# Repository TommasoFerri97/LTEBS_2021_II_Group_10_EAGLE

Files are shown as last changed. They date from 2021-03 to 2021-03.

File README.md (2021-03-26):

# Electronic technologies and biosensors laboratory
> 2021 - II semester - First Assignment

## Authors (Group 10)
  - [**Dario Comini**](https://github.com/DarioComini) 
  - [**Tommaso Ferri**](https://github.com/TommasoFerri97)

## Description
Design a schematic, a PCB, and custom devices using Autodesk EAGLE software.

### Context
Your company, the LTEBS srl, would like to use the PSoC 5LP micro-controller in a project requested by a customer. In order to evaluate the performance of the micro-controller and to determine if such uC is suitable for the project, the R&D department would like to design a PCB embedding the PSoC 5LP. This way, testing and assessment of the performance would be a lot easier than using a simple breadboard. As Cypress offers a development kit for the PSoC 5LP, namely the CY8CKIT-059, you are requested to design a PCB embedding suck kit, which will be soldered on male jumpers, and additional components required to conduct the proper testing by the R&D department. As some of the requested components are not present in EAGLE installation libraries, you are required to design a library containing such components. The PCB will be manufactured by [MDSrl](https://www.mdsrl.it/).

Starting from a schematic and a list of components, create the associated PCB. Route all the components, and check that the ratsnest command does not provide any error message. Create a design rule files according to the technical specifications reported in the manufacturer website. Perform a DRC (Design Rule Check) using the created DRC file and check that no error or warning is generated.

### Repository structure
- **Library**: Contains EAGLE library files
  - *"Group_10_Library.lbr"*: library file for devices [TMUX1208](https://www.ti.com/lit/ds/symlink/tmux1208.pdf) and [TCA9546A](https://www.ti.com/lit/ds/symlink/tca9546a.pdf)
- **Project**: Contains EAGLE schematic and board files
  - *"Group_10.sch"*: schematic file
  - *"Group_10.brd"*: board file
- **Design Rules**: Contains EAGLE design rules file
  - *"Group_10.dru"*: design rules file, following [manufacturer's specifications](https://www.mdsrl.it/mddesignrules.html)

### Additional resources
The following documents/tutorial can be useful for this assignment:
- [SparkFun EAGLE Tutorial](https://learn.sparkfun.com/tutorials/using-eagle-schematic/all)
- [EAGLE Layers](https://www.autodesk.com/products/eagle/blog/every-layer-explained-autodesk-eagle/)
- [Getting Started with EAGLE](https://www.autodesk.com/products/eagle/overview)

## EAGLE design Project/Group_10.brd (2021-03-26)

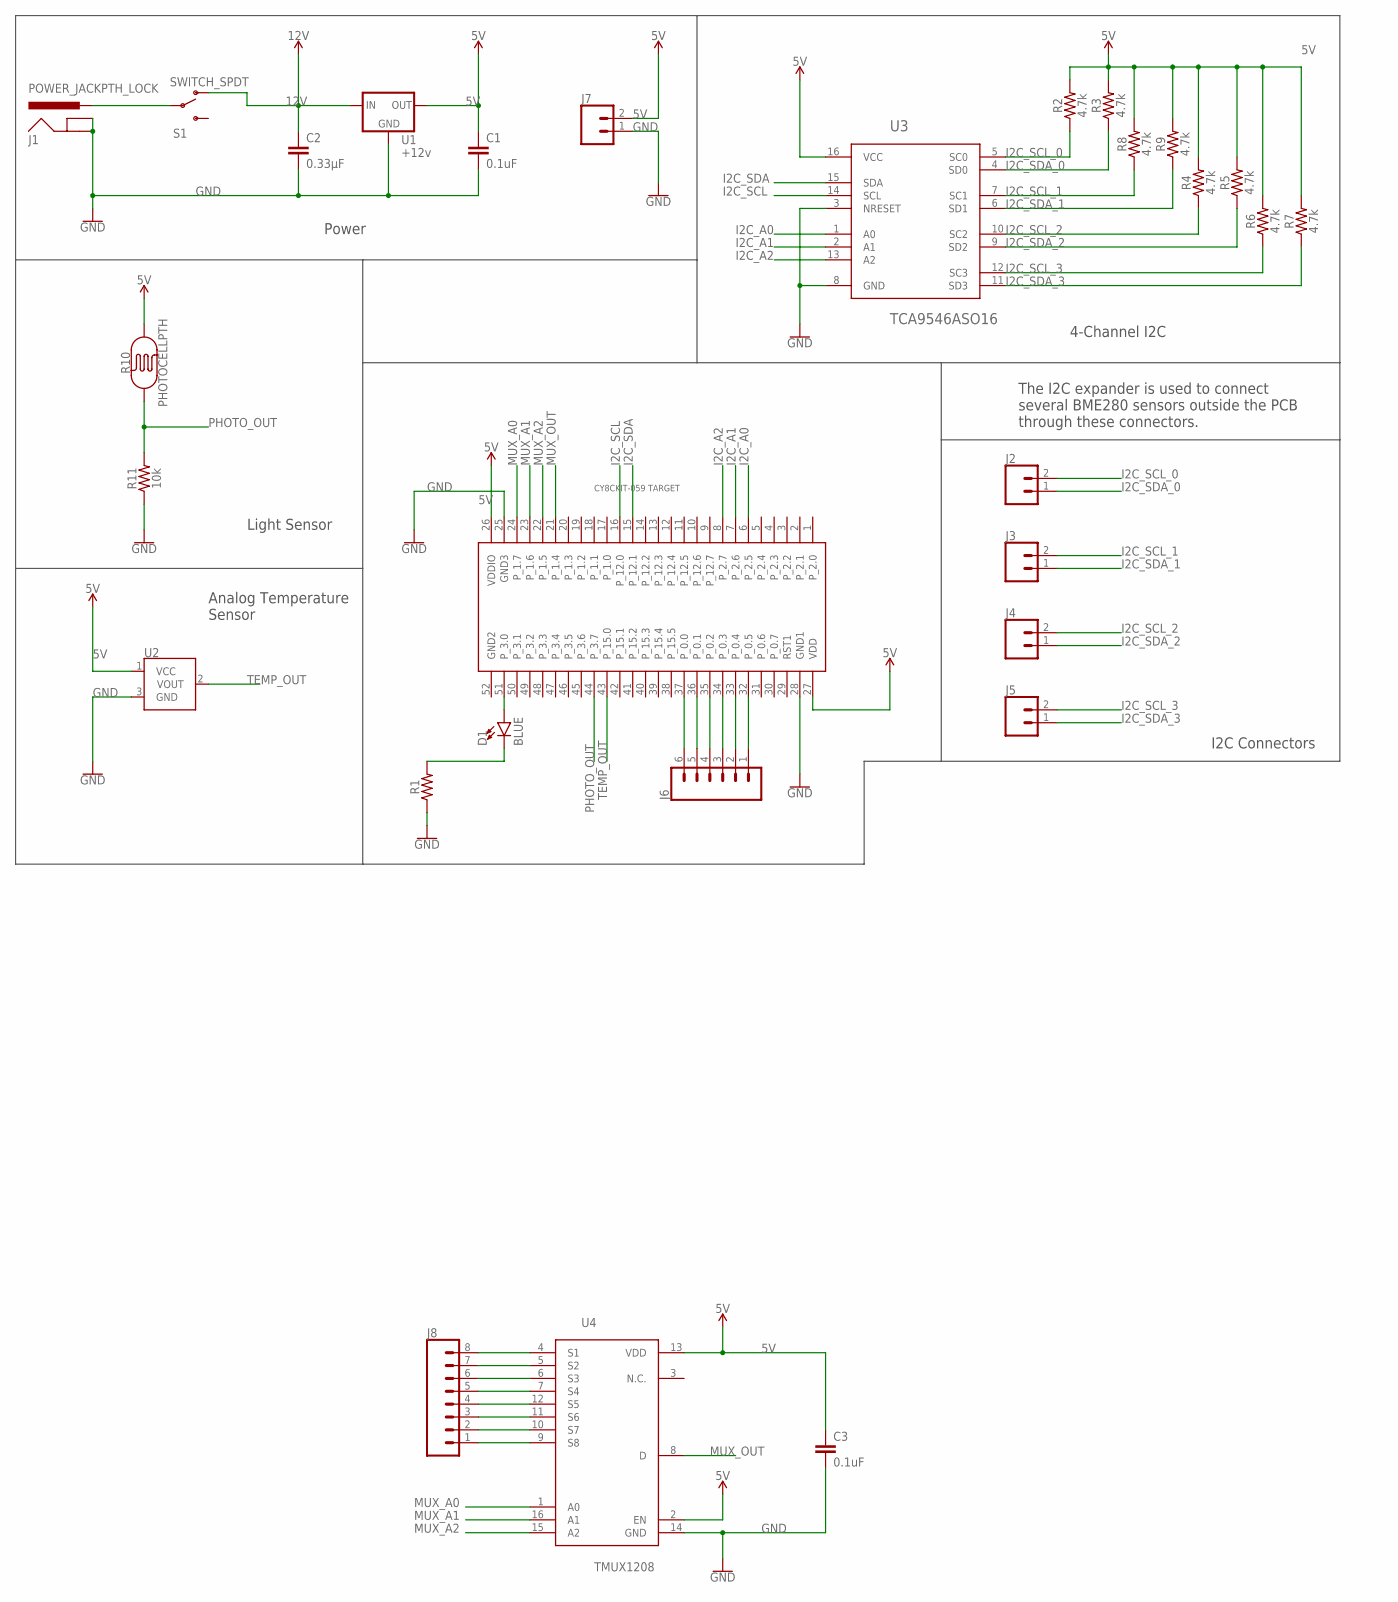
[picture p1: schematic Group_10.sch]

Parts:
C1, C3: 0.1uF; CAP-PTH-SMALL-KIT
C2: 0.33µF; 0805
D1: BLUE; LED-1206
J1: POWER_JACKPTH_LOCK; POWER_JACK_PTH_LOCK
J2, J3, J4, J5, J7: CONN_02; 1X02
J6: CONN_06LOCK; 1X06_LOCK
J8: CONN_08"; 1X08
R1: AXIAL-0.3
R2, R3, R4, R5, R6, R7, R8, R9: 4.7k; 0603
R10: PHOTOCELLPTH; PHOTOCELL
R11: 10k; 0603
S1: SWITCH_SPDT; KPS-1290
U1: +12v; TO-252
U2: TMP36GT9; TO-92
U3: TCA9546ASO16; TSSOP16
U4: TMUX1208; QFN16
U$2: CY8CKIT-059_TARGET_3

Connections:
5V: C1.1, C3.1, J7.2, R2.2, R3.2, R4.2, R5.2, R6.2, R7.2, R8.2, R9.2, R10.2, U1.2 (OUT), U2.1 (VCC), U3.16 (VCC), U4.2 (EN), U4.13 (VDD), U$2.26 (VDDIO), U$2.27 (VDD)
12V: C2.1, S1.O, U1.1 (IN)
GND: C1.2, C2.2, C3.2, J1.GND, J1.GNDBREAK, J7.1, R1.P$1 (1), R11.1, U1.3 (GND), U2.3 (GND), U3.3 (NRESET), U3.8 (GND), U4.14 (GND), U$2.25 (GND3), U$2.28 (GND1)
GND2: U$2.52 (GND2)
I2C_A0: U3.1 (A0), U$2.6 (P_2.5)
I2C_A1: U3.2 (A1), U$2.7 (P_2.6)
I2C_A2: U3.13 (A2), U$2.8 (P_2.7)
I2C_SCL: U3.14 (SCL), U$2.16 (P_12.0)
I2C_SCL_0: J2.2, R2.1, U3.5 (SC0)
I2C_SCL_1: J3.2, R8.1, U3.7 (SC1)
I2C_SCL_2: J4.2, R4.1, U3.10 (SC2)
I2C_SCL_3: J5.2, R6.1, U3.12 (SC3)
I2C_SDA: U3.15 (SDA), U$2.15 (P_12.1)
I2C_SDA_0: J2.1, R3.1, U3.4 (SD0)
I2C_SDA_1: J3.1, R9.1, U3.6 (SD1)
I2C_SDA_2: J4.1, R5.1, U3.9 (SD2)
I2C_SDA_3: J5.1, R7.1, U3.11 (SD3)
MUX_A0: U4.1 (A0), U$2.24 (P_1.7)
MUX_A1: U4.16 (A1), U$2.23 (P_1.6)
MUX_A2: U4.15 (A2), U$2.22 (P_1.5)
MUX_OUT: U4.8 (D), U$2.21 (P_1.4)
unnamed: J1.PWR, S1.P
unnamed: D1.A, U$2.51 (P_3.0)
unnamed: D1.C, R1.P$2 (2)
unnamed: J6.1, U$2.32 (P_0.5)
unnamed: J6.2, U$2.33 (P_0.4)
unnamed: J6.3, U$2.34 (P_0.3)
unnamed: J6.4, U$2.35 (P_0.2)
unnamed: J6.5, U$2.36 (P_0.1)
unnamed: J6.6, U$2.37 (P_0.0)
unnamed: J8.8, U4.4 (S1)
unnamed: J8.7, U4.5 (S2)
unnamed: J8.6, U4.6 (S3)
unnamed: J8.5, U4.7 (S4)
unnamed: J8.4, U4.12 (S5)
unnamed: J8.3, U4.11 (S6)
unnamed: J8.2, U4.10 (S7)
unnamed: J8.1, U4.9 (S8)
PHOTO_OUT: R10.1, R11.2, U$2.44 (P_3.7)
TEMP_OUT: U2.2 (VOUT), U$2.43 (P_15.0)

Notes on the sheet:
4-Channel I2C
Power
Light Sensor
Analog Temperature Sensor
I2C Connectors
The I2C expander is used to connect several BME280 sensors outside the PCB through these connectors.

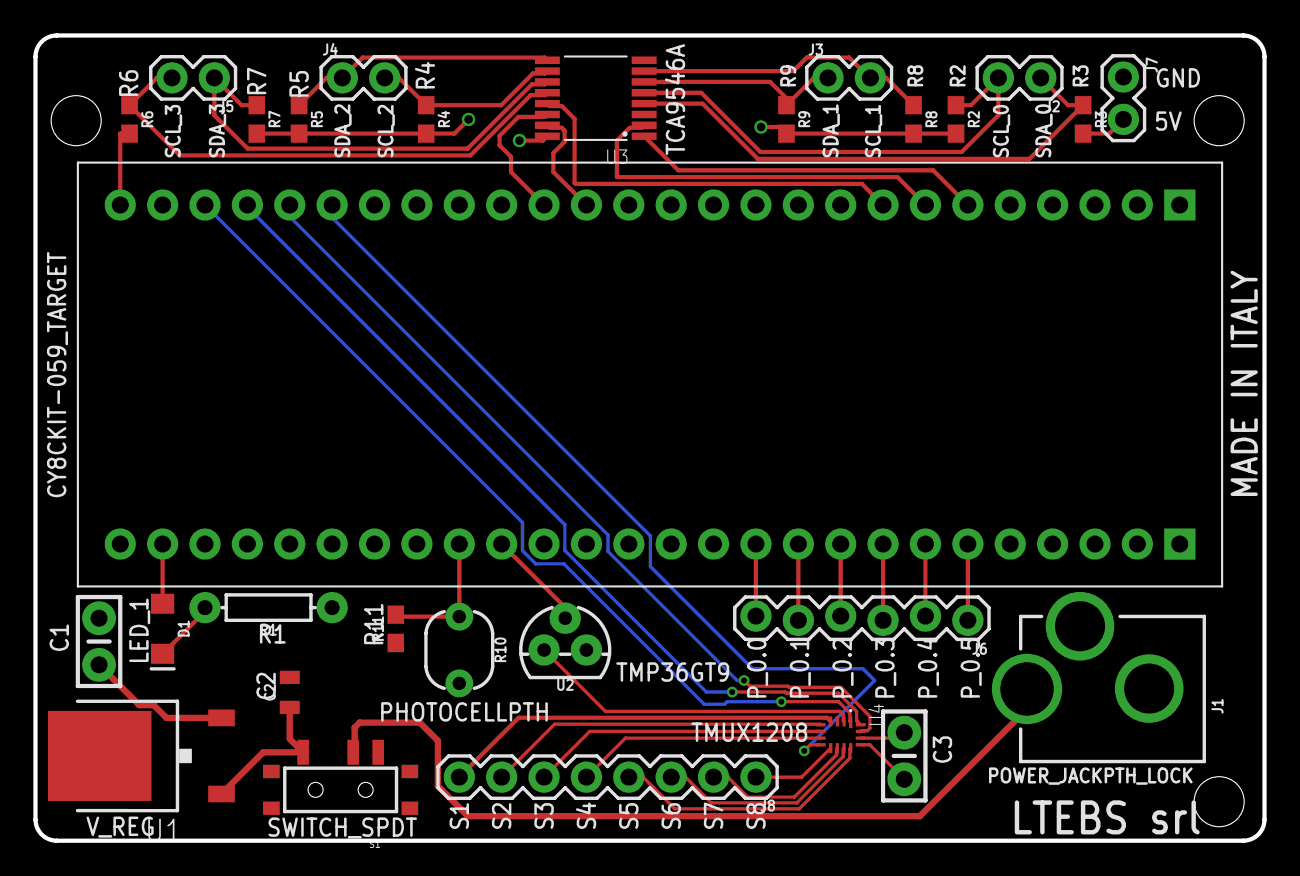
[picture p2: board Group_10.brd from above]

Board: 2 copper layers, 73.7 x 48.3 mm, 29 parts (0 on the bottom side), 39 nets.

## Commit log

2021-03-18 first commit - added schematic file with some components
    [Group_10.sch]
2021-03-18 created footprint QFN16
2021-03-18 TMUX1208 device added with description to the new created library
2021-03-19 full schematic without TCA9546A
2021-03-19 removed schematic backups from tracking and corrected gitignore to exclude further schematic backups
2021-03-19 TCA9546A device added with description to the library
2021-03-19 Added device TCA9546A to schematic and added value to R1
    [Group_10.sch]
2021-03-20 added board file and connected all components
    [Group_10.brd]
2021-03-20 added exclusion rule for board backup files in gitignore
2021-03-21 added silkscreen on top and bottom side to help in the main components placement
    [Group_10.brd]
2021-03-22 corrected devices silkscreen distance from pads to match manifacturer's
2021-03-22 Updated devices on board, corrected isolate of copper pour, simplified some routing
    [Group_10.brd, Group_10.sch]
2021-03-22 Corrected silkscreen font width to match manifacturer's, added some information and corrected some routing
    [Group_10.brd]
2021-03-22 Corrected I2C_SDA_2 serigraphy
    [Group_10.brd]
2021-03-22 Added M3 holes
    [Group_10.brd]
2021-03-22 Increased width of power traces for possible current requirements
    [Group_10.brd]
2021-03-22 added comments to the schematic
    [Group_10.sch]
2021-03-23 Added smooth angles to the board
    [Group_10.brd]
2021-03-23 Fixed device description and added link to datasheet
2021-03-23 Added silkscreen watermarks
    [Group_10.brd]
2021-03-26 Corrected an error in schematic that caused some MUX connections to not be reflected in the board. Then connected them in the board
    [Group_10.brd, Group_10.sch]
2021-03-26 Moved second frame to a second sheet
    [Group_10.sch]

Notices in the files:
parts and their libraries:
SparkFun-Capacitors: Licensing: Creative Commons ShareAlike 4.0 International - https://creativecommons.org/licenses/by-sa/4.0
